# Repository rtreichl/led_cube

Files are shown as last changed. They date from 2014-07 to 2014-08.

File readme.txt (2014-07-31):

TODOs and Thoughts

switch programm {
case 0:
	programm += cube_rot(&index, &cube, ....);
	break;
case 1:
	programm += cube_shift(&index, &cube, ....);
	break;
........
};

Selfshifting architecture!!! (see above)
Try to make a cmake project!!
All configurations should be included in one file!!
Use Doxigen write-style for comments (very important! will be used for generate a automatically documentation)
Use C-programmes instead of model-data-structure. (Not enough Space avalible!!!)
Try to use BT-connection for a PC-controled mode!!! (messaure time delay between PC <-> µC)
Programm rotated output, this means move base which is bottom to left, right, front, back and top!!!
Output functions can be controlled from animation functions, this means output functions were called over function pointer,
which were set from animations function.
All output, animation functions must have the same Parameterlist, use void pointer to access them with different data!
Try to implement a section programing interface instead of a pagewise one!
Bootloader should have a login interface too!
Optimize BT-Interface for terminal. (Maybe Login & Pwd Login)
Write a Android app for controll the actually shown programm.(programm = bt_android_code(....))
Reprogramm global time base can be accessed from any part in programm but should be not global use pointer!!!
PC-programm has to be included a serial-interface (requires a bluetooth driver that includes a serial to bluetooth interface)
Usefull options for PC-programm could be a compile option + including the resulting object file to simulate!!! (Not sure if this would work)
Move GIT repository from Cloudforge to Github.(Done!)
Maybe try to make a second version of board which includes a Cortex-M0 µC or something like this.(Problem is requires a new Programmer!)
Redesinge some layout faults from first version of board (new placement of pinheader, change all voltage regulators, ....)

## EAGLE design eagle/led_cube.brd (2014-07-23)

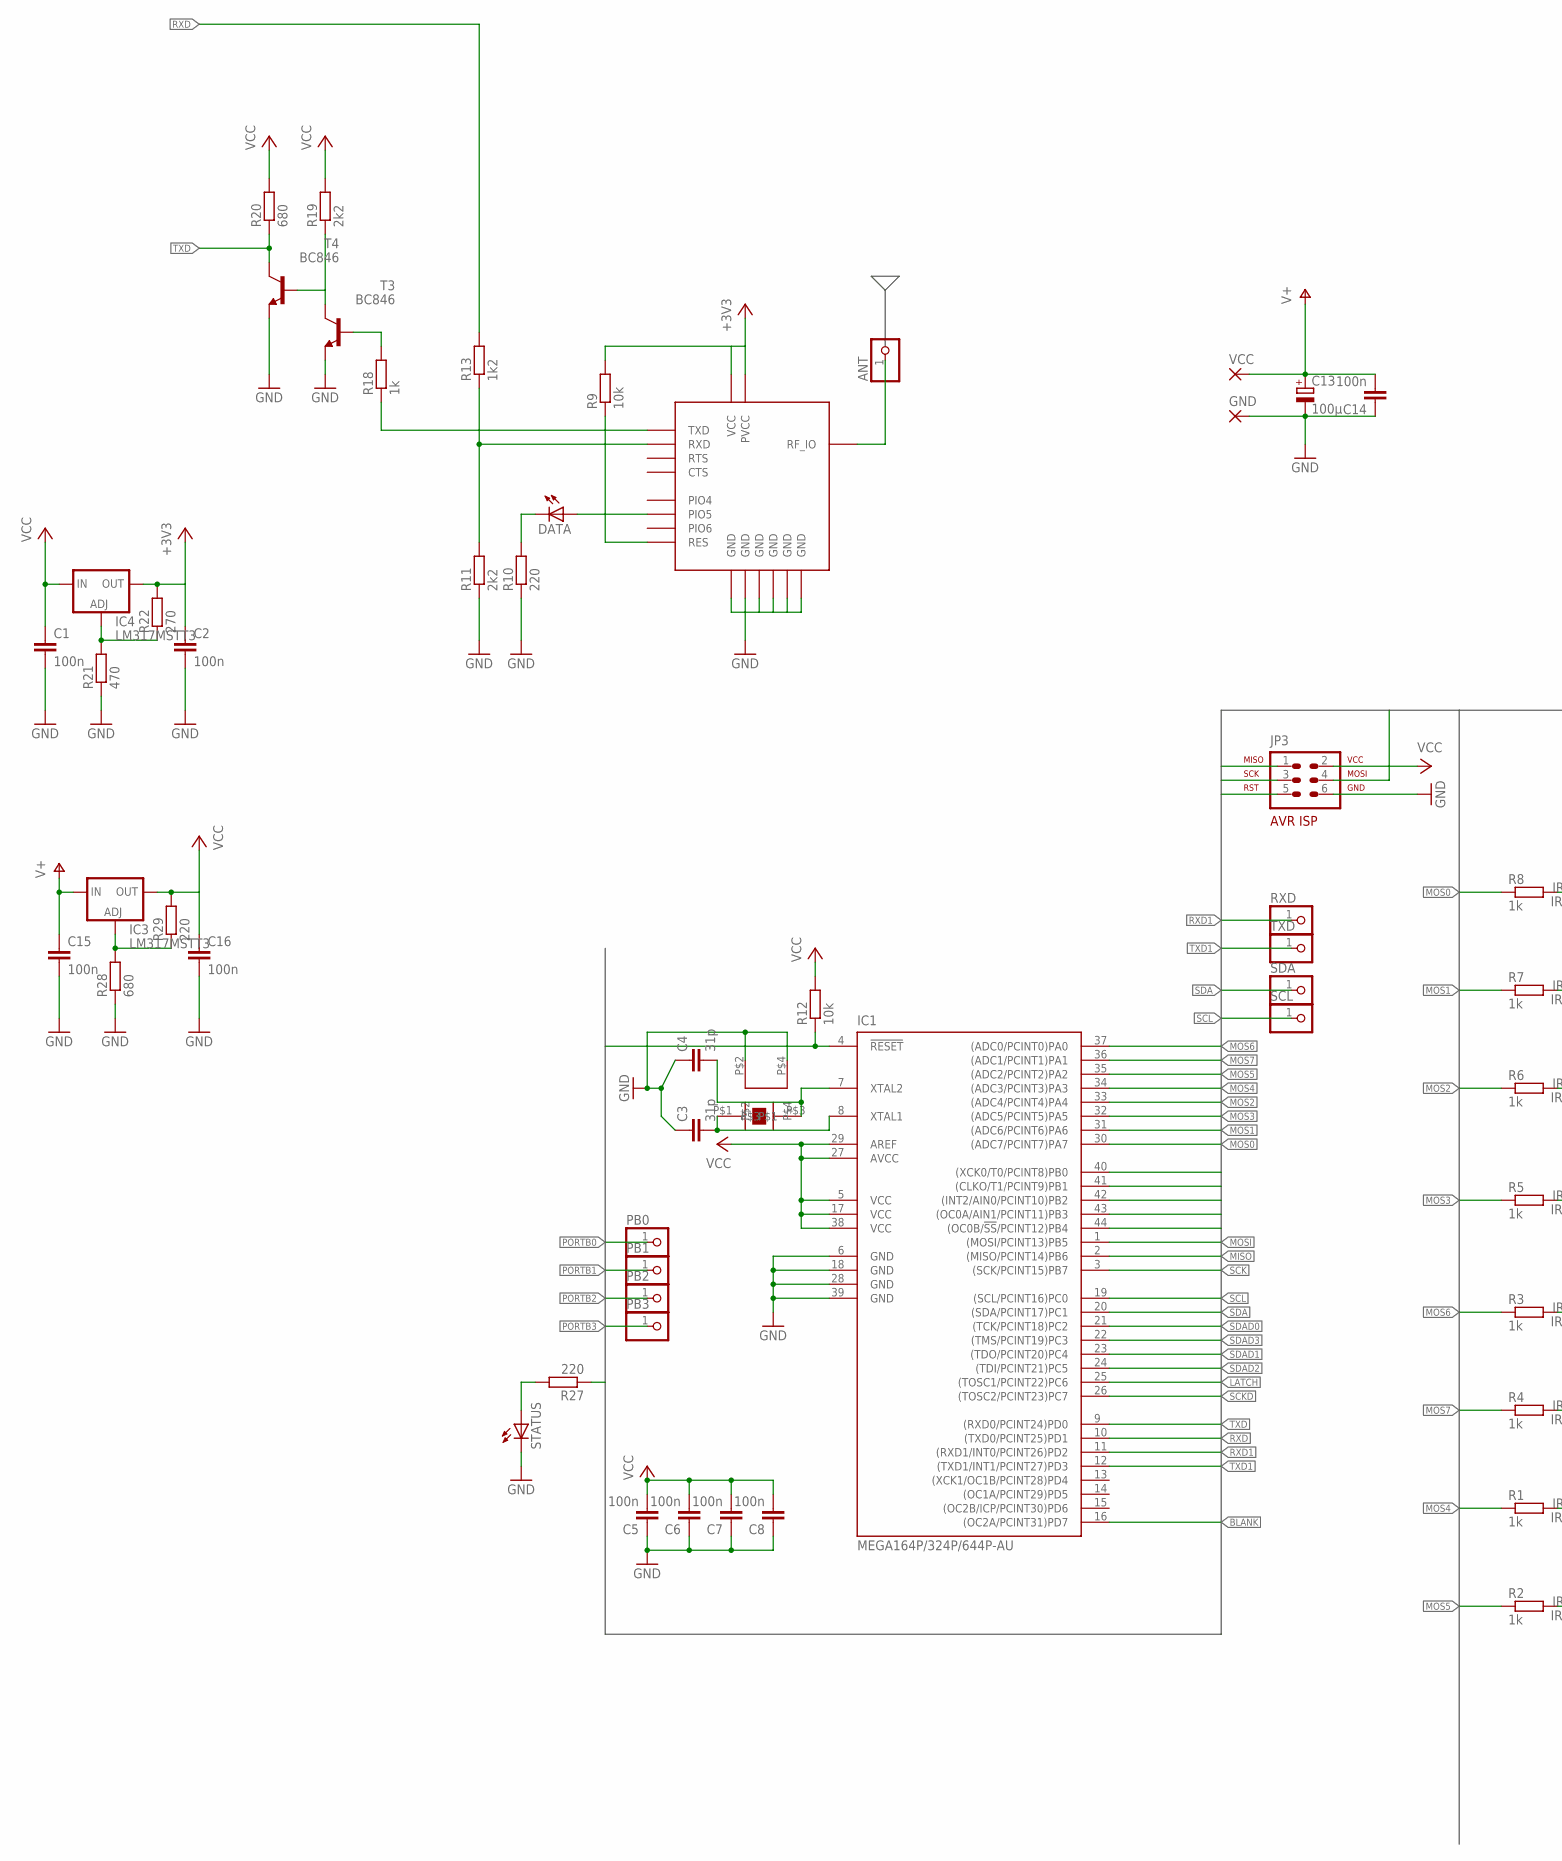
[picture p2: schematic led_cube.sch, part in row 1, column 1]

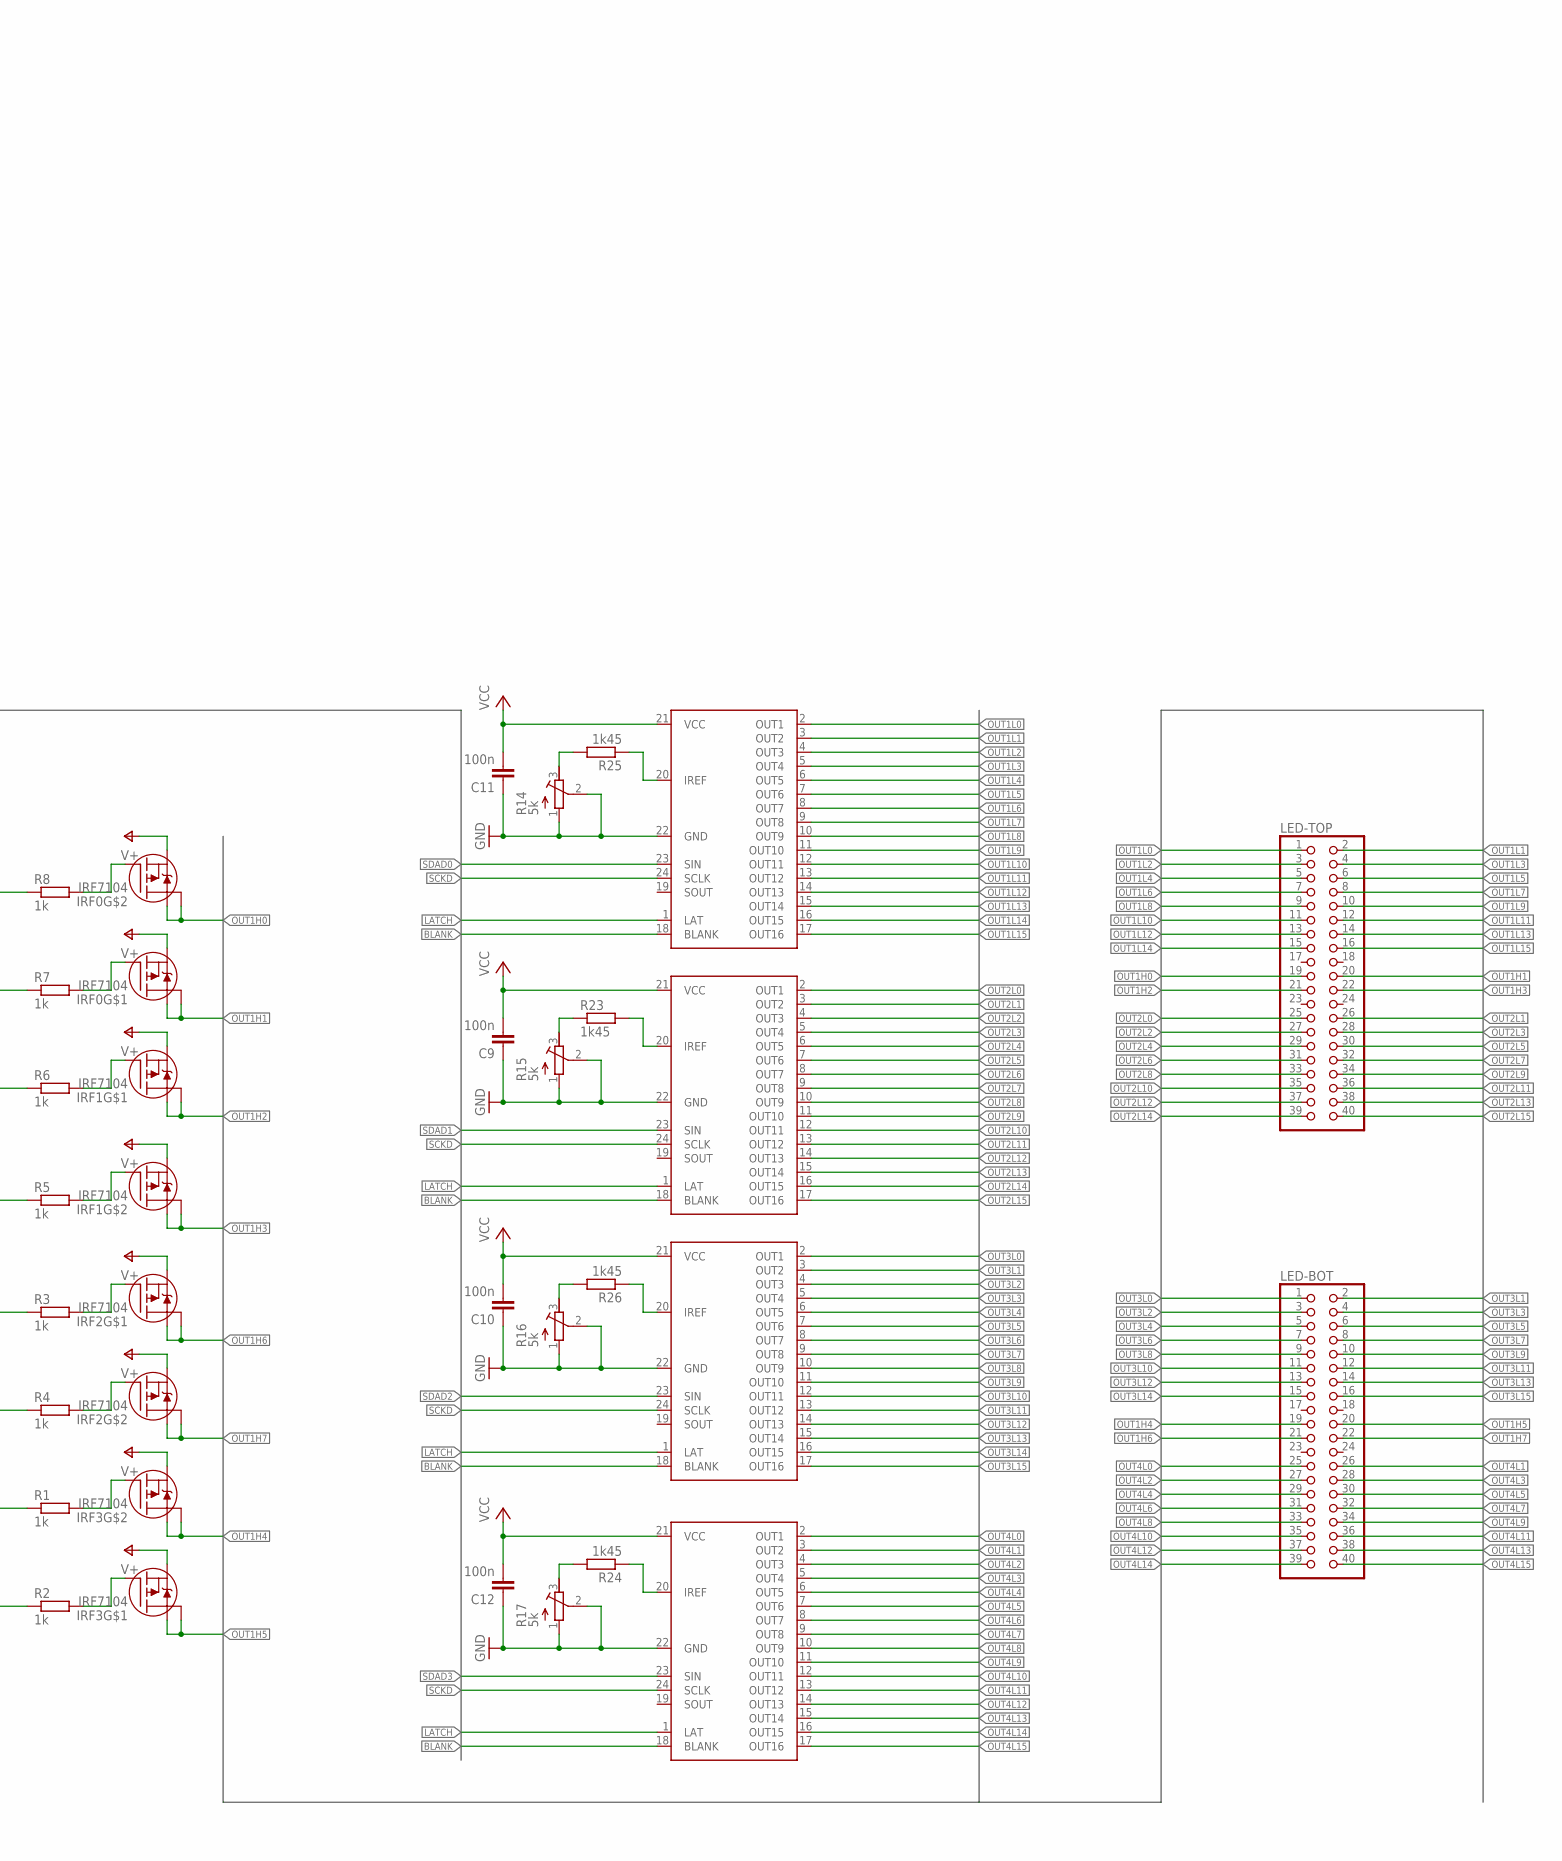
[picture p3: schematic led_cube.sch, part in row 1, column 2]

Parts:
ANT: PINHD-1X1; 1X01
C1, C2, C5, C6, C7, C8, C9, C10, C11, C12, C14, C15, C16: 100n; C0805
C3, C4: 31p; C0805
C13: 100µ; PANASONIC_D
DATA: LEDCHIPLED_1206; CHIPLED_1206
GND: 2,54/1,0
IC1: MEGA164P/324P/644P-AU; TQFP44
IC2: BTM_SER; BTM_222
IC3, IC4: LM317MSTT3; SOT223
IRF0, IRF1, IRF2, IRF3: IRF7104; SO8-2
JP3: AVR-ISP-6VERT; AVR-ISP-6
LED-BOT: PINHD-2X20; 2X20
LED-TOP: PINHD-2X20; 2X20
PB0, PB1, PB2, PB3: PINHD-1X1; 1X01
R1, R2, R3, R4, R5, R6, R7, R8, R18: 1k; R0805
R9, R12: 10k; R0805
R10, R27, R29: 220; R0805
R11, R19: 2k2; R0805
R13: 1k2; R0805
R14, R15, R16, R17: 5k; RTRIM3202
R20, R28: 680; R0805
R21: 470; R0805
R22: 270; R0805
R23, R24, R25, R26: 1k45; R0805
RXD: PINHD-1X1; 1X01
SCL: PINHD-1X1; 1X01
SDA: PINHD-1X1; 1X01
STATUS: LEDCHIPLED_1206; CHIPLED_1206
T3, T4: BC846; SOT23
TLC0, TLC1, TLC2, TLC3: TLC5929RGE; HVQFN24
TXD: PINHD-1X1; 1X01
U$9: ABMM2
VCC: 2,54/1,0

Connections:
+3V3: C2.1, IC2.P$2 (PVCC), IC2.P$17 (VCC), IC4.4 (OUT), R9.2, R22.2
BLANK: IC1.16 ((OC2A/PCINT31)PD7), TLC0.18 (BLANK), TLC1.18 (BLANK), TLC2.18 (BLANK), TLC3.18 (BLANK)
GND: C1.2, C2.2, C3.1, C4.1, C5.1, C6.1, C7.1, C8.1, C9.1, C10.1, C11.1, C12.1, C13.-, C14.1, C15.2, C16.2, GND.1, IC1.6 (GND), IC1.18 (GND), IC1.28 (GND), IC1.39 (GND), IC2.P$1 (GND), IC2.P$10 (GND), IC2.P$18 (GND), IC2.P$19 (GND), IC2.P$29 (GND), IC2.P$38 (GND), JP3.6, R10.1, R11.1, R14.1 (A), R14.2 (S), R15.1 (A), R15.2 (S), R16.1 (A), R16.2 (S), R17.1 (A), R17.2 (S), R21.1, R28.1, STATUS.C, T3.2 (E), T4.2 (E), TLC0.22 (GND), TLC1.22 (GND), TLC2.22 (GND), TLC3.22 (GND), U$9.P$2, U$9.P$4
LATCH: IC1.25 ((TOSC1/PCINT22)PC6), TLC0.1 (LAT), TLC1.1 (LAT), TLC2.1 (LAT), TLC3.1 (LAT)
MISO: IC1.2 ((MISO/PCINT14)PB6), JP3.1
MOS0: IC1.30 ((ADC7/PCINT7)PA7), R8.1
MOS1: IC1.31 ((ADC6/PCINT6)PA6), R7.1
MOS2: IC1.33 ((ADC4/PCINT4)PA4), R6.1
MOS3: IC1.32 ((ADC5/PCINT5)PA5), R5.1
MOS4: IC1.34 ((ADC3/PCINT3)PA3), R1.1
MOS5: IC1.35 ((ADC2/PCINT2)PA2), R2.1
MOS6: IC1.37 ((ADC0/PCINT0)PA0), R3.1
MOS7: IC1.36 ((ADC1/PCINT1)PA1), R4.1
MOSI: IC1.1 ((MOSI/PCINT13)PB5), JP3.4
unnamed: C3.2, IC1.8 (XTAL1), U$9.P$1
unnamed: IC2.P$26 (RXD), R11.2, R13.1
unnamed: C4.2, IC1.7 (XTAL2), U$9.P$3
unnamed: IRF3.2 (G), R2.2
unnamed: IC2.P$16 (RES), R9.1
unnamed: DATA.A, IC2.P$11 (PIO5)
unnamed: DATA.C, R10.2
unnamed: IRF3.4 (G), R1.2
unnamed: IRF2.4 (G), R4.2
unnamed: IC2.P$27 (TXD), R18.1
unnamed: R18.2, T3.1 (B)
unnamed: R19.1, T3.3 (C), T4.1 (B)
unnamed: IRF2.2 (G), R3.2
unnamed: IC4.1 (ADJ), R21.2, R22.1
unnamed: IRF1.4 (G), R5.2
unnamed: IRF1.2 (G), R6.2
unnamed: IRF0.2 (G), R7.2
unnamed: IRF0.4 (G), R8.2
unnamed: R24.1, TLC3.20 (IREF)
unnamed: R17.3 (E), R24.2
unnamed: R16.3 (E), R26.2
unnamed: R26.1, TLC2.20 (IREF)
unnamed: R23.2, TLC1.20 (IREF)
unnamed: R15.3 (E), R23.1
unnamed: R14.3 (E), R25.2
unnamed: R25.1, TLC0.20 (IREF)
unnamed: ANT.1, IC2.P$37 (RF_IO)
unnamed: R27.2, STATUS.A
unnamed: IC3.1 (ADJ), R28.2, R29.1
OUT1H0: IRF0.5 (D), IRF0.6 (D), LED-TOP.19
OUT1H1: IRF0.7 (D), IRF0.8 (D), LED-TOP.20
OUT1H2: IRF1.7 (D), IRF1.8 (D), LED-TOP.21
OUT1H3: IRF1.5 (D), IRF1.6 (D), LED-TOP.22
OUT1H4: IRF3.5 (D), IRF3.6 (D), LED-BOT.19
OUT1H5: IRF3.7 (D), IRF3.8 (D), LED-BOT.20
OUT1H6: IRF2.7 (D), IRF2.8 (D), LED-BOT.21
OUT1H7: IRF2.5 (D), IRF2.6 (D), LED-BOT.22
OUT1L0: LED-TOP.1, TLC0.2 (OUT1)
OUT1L1: LED-TOP.2, TLC0.3 (OUT2)
OUT1L2: LED-TOP.3, TLC0.4 (OUT3)
OUT1L3: LED-TOP.4, TLC0.5 (OUT4)
OUT1L4: LED-TOP.5, TLC0.6 (OUT5)
OUT1L5: LED-TOP.6, TLC0.7 (OUT6)
OUT1L6: LED-TOP.7, TLC0.8 (OUT7)
OUT1L7: LED-TOP.8, TLC0.9 (OUT8)
OUT1L8: LED-TOP.9, TLC0.10 (OUT9)
OUT1L9: LED-TOP.10, TLC0.11 (OUT10)
OUT1L10: LED-TOP.11, TLC0.12 (OUT11)
OUT1L11: LED-TOP.12, TLC0.13 (OUT12)
OUT1L12: LED-TOP.13, TLC0.14 (OUT13)
OUT1L13: LED-TOP.14, TLC0.15 (OUT14)
OUT1L14: LED-TOP.15, TLC0.16 (OUT15)
OUT1L15: LED-TOP.16, TLC0.17 (OUT16)
OUT2L0: LED-TOP.25, TLC1.2 (OUT1)
OUT2L1: LED-TOP.26, TLC1.3 (OUT2)
OUT2L2: LED-TOP.27, TLC1.4 (OUT3)
OUT2L3: LED-TOP.28, TLC1.5 (OUT4)
OUT2L4: LED-TOP.29, TLC1.6 (OUT5)
OUT2L5: LED-TOP.30, TLC1.7 (OUT6)
OUT2L6: LED-TOP.31, TLC1.8 (OUT7)
OUT2L7: LED-TOP.32, TLC1.9 (OUT8)
OUT2L8: LED-TOP.33, TLC1.10 (OUT9)
OUT2L9: LED-TOP.34, TLC1.11 (OUT10)
OUT2L10: LED-TOP.35, TLC1.12 (OUT11)
OUT2L11: LED-TOP.36, TLC1.13 (OUT12)
OUT2L12: LED-TOP.37, TLC1.14 (OUT13)
OUT2L13: LED-TOP.38, TLC1.15 (OUT14)
OUT2L14: LED-TOP.39, TLC1.16 (OUT15)
OUT2L15: LED-TOP.40, TLC1.17 (OUT16)
OUT3L0: LED-BOT.1, TLC2.2 (OUT1)
OUT3L1: LED-BOT.2, TLC2.3 (OUT2)
OUT3L2: LED-BOT.3, TLC2.4 (OUT3)
OUT3L3: LED-BOT.4, TLC2.5 (OUT4)
OUT3L4: LED-BOT.5, TLC2.6 (OUT5)
OUT3L5: LED-BOT.6, TLC2.7 (OUT6)
OUT3L6: LED-BOT.7, TLC2.8 (OUT7)
OUT3L7: LED-BOT.8, TLC2.9 (OUT8)
OUT3L8: LED-BOT.9, TLC2.10 (OUT9)
OUT3L9: LED-BOT.10, TLC2.11 (OUT10)
OUT3L10: LED-BOT.11, TLC2.12 (OUT11)
OUT3L11: LED-BOT.12, TLC2.13 (OUT12)
OUT3L12: LED-BOT.13, TLC2.14 (OUT13)
OUT3L13: LED-BOT.14, TLC2.15 (OUT14)
OUT3L14: LED-BOT.15, TLC2.16 (OUT15)
OUT3L15: LED-BOT.16, TLC2.17 (OUT16)
OUT4L0: LED-BOT.25, TLC3.2 (OUT1)
OUT4L1: LED-BOT.26, TLC3.3 (OUT2)
OUT4L2: LED-BOT.27, TLC3.4 (OUT3)
OUT4L3: LED-BOT.28, TLC3.5 (OUT4)
OUT4L4: LED-BOT.29, TLC3.6 (OUT5)
OUT4L5: LED-BOT.30, TLC3.7 (OUT6)
OUT4L6: LED-BOT.31, TLC3.8 (OUT7)
OUT4L7: LED-BOT.32, TLC3.9 (OUT8)
OUT4L8: LED-BOT.33, TLC3.10 (OUT9)
OUT4L9: LED-BOT.34, TLC3.11 (OUT10)
OUT4L10: LED-BOT.35, TLC3.12 (OUT11)
OUT4L11: LED-BOT.36, TLC3.13 (OUT12)
OUT4L12: LED-BOT.37, TLC3.14 (OUT13)
OUT4L13: LED-BOT.38, TLC3.15 (OUT14)
OUT4L14: LED-BOT.39, TLC3.16 (OUT15)
OUT4L15: LED-BOT.40, TLC3.17 (OUT16)
PORTB0: IC1.40 ((XCK0/T0/PCINT8)PB0), PB0.1
PORTB1: IC1.41 ((CLKO/T1/PCINT9)PB1), PB1.1
PORTB2: IC1.42 ((INT2/AIN0/PCINT10)PB2), PB2.1
PORTB3: IC1.43 ((OC0A/AIN1/PCINT11)PB3), PB3.1
PORTB4: IC1.44 ((OC0B/!SS!/PCINT12)PB4), R27.1
RST: IC1.4 (!RESET), JP3.5, R12.1
RXD: IC1.10 ((TXD0/PCINT25)PD1), R13.2
RXD1: IC1.11 ((RXD1/INT0/PCINT26)PD2), RXD.1
SCK: IC1.3 ((SCK/PCINT15)PB7), JP3.3
SCKD: IC1.26 ((TOSC2/PCINT23)PC7), TLC0.24 (SCLK), TLC1.24 (SCLK), TLC2.24 (SCLK), TLC3.24 (SCLK)
SCL: IC1.19 ((SCL/PCINT16)PC0), SCL.1
SDA: IC1.20 ((SDA/PCINT17)PC1), SDA.1
SDAD0: IC1.21 ((TCK/PCINT18)PC2), TLC0.23 (SIN)
SDAD1: IC1.23 ((TDO/PCINT20)PC4), TLC1.23 (SIN)
SDAD2: IC1.24 ((TDI/PCINT21)PC5), TLC2.23 (SIN)
SDAD3: IC1.22 ((TMS/PCINT19)PC3), TLC3.23 (SIN)
TXD: IC1.9 ((RXD0/PCINT24)PD0), R20.1, T4.3 (C)
TXD1: IC1.12 ((TXD1/INT1/PCINT27)PD3), TXD.1
V+: C13.+, C14.2, C15.1, IC3.3 (IN), IRF0.1 (S), IRF0.3 (S), IRF1.1 (S), IRF1.3 (S), IRF2.1 (S), IRF2.3 (S), IRF3.1 (S), IRF3.3 (S), VCC.1
VCC: C1.1, C5.2, C6.2, C7.2, C8.2, C9.2, C10.2, C11.2, C12.2, C16.1, IC1.5 (VCC), IC1.17 (VCC), IC1.27 (AVCC), IC1.29 (AREF), IC1.38 (VCC), IC3.4 (OUT), IC4.3 (IN), JP3.2, R12.2, R19.2, R20.2, R29.2, TLC0.21 (VCC), TLC1.21 (VCC), TLC2.21 (VCC), TLC3.21 (VCC)

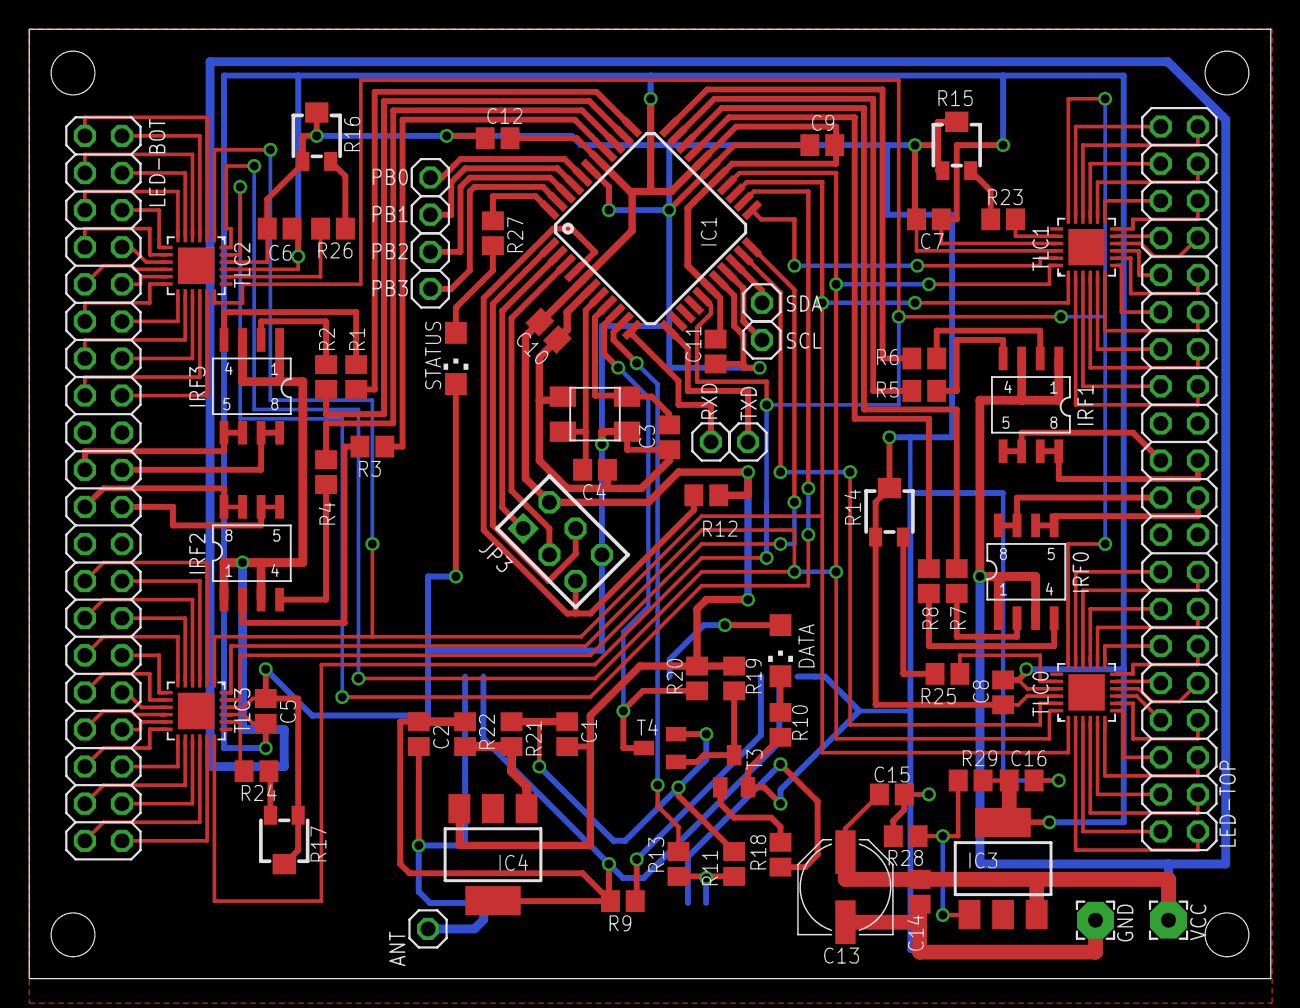
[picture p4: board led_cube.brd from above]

Board: 2 copper layers, 85.0 x 65.0 mm, 76 parts (1 on the bottom side), 135 nets.

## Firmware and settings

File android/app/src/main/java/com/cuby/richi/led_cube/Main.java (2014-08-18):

package com.cuby.richi.led_cube;

import android.app.Activity;

import android.app.ActionBar;
import android.app.Fragment;
import android.app.FragmentManager;
import android.content.Context;
import android.os.Build;
import android.os.Bundle;
import android.view.Gravity;
import android.view.LayoutInflater;
import android.view.Menu;
import android.view.MenuItem;
import android.view.View;
import android.view.ViewGroup;
import android.support.v4.widget.DrawerLayout;
import android.widget.ArrayAdapter;
import android.widget.TextView;


public class Main extends Activity
        implements NavigationDrawerFragment.NavigationDrawerCallbacks {

    /**
     * Fragment managing the behaviors, interactions and presentation of the navigation drawer.
     */
    private NavigationDrawerFragment mNavigationDrawerFragment;

    /**
     * Used to store the last screen title. For use in {@link #restoreActionBar()}.
     */
    private CharSequence mTitle;

    @Override
    protected void onCreate(Bundle savedInstanceState) {
        super.onCreate(savedInstanceState);
        setContentView(R.layout.activity_main);

        mNavigationDrawerFragment = (NavigationDrawerFragment)
                getFragmentManager().findFragmentById(R.id.navigation_drawer);
        mTitle = getTitle();

        // Set up the drawer.
        mNavigationDrawerFragment.setUp(
                R.id.navigation_drawer,
                (DrawerLayout) findViewById(R.id.drawer_layout));
    }

    @Override
    public void onNavigationDrawerItemSelected(int position) {
        // update the main content by replacing fragments
        FragmentManager fragmentManager = getFragmentManager();
        fragmentManager.beginTransaction()
                .replace(R.id.container, PlaceholderFragment.newInstance(position + 1))
                .commit();
    }

    public void onSectionAttached(int number) {
        switch (number) {
            case 1:
                mTitle = getString(R.string.title_section1);
                break;
            case 2:
                mTitle = getString(R.string.title_section2);
                break;
            case 3:
                mTitle = getString(R.string.title_section3);
                break;
        }
    }

    public void restoreActionBar() {
        ActionBar actionBar = getActionBar();
        actionBar.setNavigationMode(ActionBar.NAVIGATION_MODE_STANDARD);
        actionBar.setDisplayShowTitleEnabled(true);
        actionBar.setTitle(mTitle);
    }


    @Override
    public boolean onCreateOptionsMenu(Menu menu) {
        if (!mNavigationDrawerFragment.isDrawerOpen()) {
            // Only show items in the action bar relevant to this screen
            // if the drawer is not showing. Otherwise, let the drawer
            // decide what to show in the action bar.
            getMenuInflater().inflate(R.menu.main, menu);
            restoreActionBar();
            return true;
        }
        return super.onCreateOptionsMenu(menu);
    }

    @Override
    public boolean onOptionsItemSelected(MenuItem item) {
        // Handle action bar item clicks here. The action bar will
        // automatically handle clicks on the Home/Up button, so long
        // as you specify a parent activity in AndroidManifest.xml.
        int id = item.getItemId();
        if (id == R.id.action_settings) {
            return true;
        }
        return super.onOptionsItemSelected(item);
    }

    /**
     * A placeholder fragment containing a simple view.
     */
    public static class PlaceholderFragment extends Fragment {
        /**
         * The fragment argument representing the section number for this
         * fragment.
         */
        private static final String ARG_SECTION_NUMBER = "section_number";

        /**
         * Returns a new instance of this fragment for the given section
         * number.
         */
        public static PlaceholderFragment newInstance(int sectionNumber) {
            PlaceholderFragment fragment = new PlaceholderFragment();
            Bundle args = new Bundle();
            args.putInt(ARG_SECTION_NUMBER, sectionNumber);
            fragment.setArguments(args);
            return fragment;
        }

        public PlaceholderFragment() {
        }

        @Override
        public View onCreateView(LayoutInflater inflater, ViewGroup container,
                Bundle savedInstanceState) {
            View rootView = inflater.inflate(R.layout.fragment_main, container, false);
            return rootView;
        }

        @Override
        public void onAttach(Activity activity) {
            super.onAttach(activity);
            ((Main) activity).onSectionAttached(
                    getArguments().getInt(ARG_SECTION_NUMBER));
        }
    }

}

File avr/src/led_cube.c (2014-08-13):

/*
 * led_cube.c
 *
 * Created: 27.04.2014 19:03:01
 *  Author: Richi
 */ 
#define F_CPU 19660800UL

#include <avr/io.h>
#include <include/uart.h>
#include <util/delay.h>
#include <avr/interrupt.h>
#include <include/tlc.h>
#include <include/btm222.h>
#include <avr/pgmspace.h>
#include <include/animation.h>
#define UART1_BAUD_RATE      19200
#define UART_BAUD_RATE     115200

volatile uint8_t timer2_count = 0;

int main(void)
{
    uint16_t c = 0, c1 = 0;
    uint8_t animation_prog = 0;
    static uint8_t animation_tmp = 0, animation_count = 0;
    static cube animation_data = {{0}};

    TCCR0A = (1 << COM0B1) | (1 << WGM00);
    TCCR0B = (1 << CS02);
    TCCR2A = (1 << WGM21);
    TCCR2B =  (1 << CS22) | (1 << CS21) | (1 << CS20);
    TIMSK2 = (1 << OCIE2A);
    OCR2A = 0x2F;
    OCR0B = 0x0A;
    DDRB |= (1 << PINB4) | (1 << PINB0);
    _delay_ms(1000);
    sei();
    btm222_init();
    uart1_init( UART_BAUD_SELECT(UART1_BAUD_RATE,F_CPU) );

    tlc_init();
		
    uart1_puts("Hallo UART\n");
    while(1)
    {
        tlc_put(&animation_data);
        if (timer2_count >= 40) {
            timer2_count = 0;
			if (animation_prog < animation_counts) {
				animation_prog += animation_func[11](&animation_data, &animation_count, &animation_tmp, 0); 
			}
			else {
				animation_prog = 0;
                timer2_count = 40;
			}
        }
        c = uart_getc();
        if (!(c & UART_NO_DATA)) {
            //OCR2A = c;
            btm222_conneciton(c);
            uart1_putc(c);
        }
        c1 = uart1_getc();
        if (!(c1 & UART_NO_DATA)) {
            //OCR0B = c1;
            uart_putc(c1);
        }
    }
}

ISR (TIMER2_COMPA_vect)
{
    timer2_count++;
};
//Counter 8bit
//Prescaler 64
//Overflows 40
//for 33ms or 30fps
//for 10ms Overflow 12

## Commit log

2014-07-23 add: eagle folder and files
    Initialisation commit from eagle files from old repo.
    [led_cube.brd, led_cube.sch]
2014-07-28 chg: reworked output from static to dynamic data.
    deleted data section
    add animation file
    adapted tlc for dynamic
    [led_cube.c, tlc.c]
2014-08-04 chg: added interface for upcoming content flow
2014-08-05 chg: improved implemtation of animation
    moved definition for function pointer from main file to animation file.
    added a new function for flow control (top value is where animation is
    completed, chang value is where tmp counting is changed from postive to
    negative)

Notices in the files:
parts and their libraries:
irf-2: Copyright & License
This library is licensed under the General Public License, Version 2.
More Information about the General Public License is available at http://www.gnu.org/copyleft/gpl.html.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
